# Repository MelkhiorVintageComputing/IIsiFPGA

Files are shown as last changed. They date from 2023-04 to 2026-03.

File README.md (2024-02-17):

# A FPGA on a IIsi PDS card...

## Goal

The goal of this repository is to be able to interface a modern (2023 era) [FPGA](https://en.wikipedia.org/wiki/Field-programmable_gate_array) with a [Macintosh IIsi](https://en.wikipedia.org/wiki/Macintosh_IIsi) using its PDS (Processor Direct Slot) connector. The PDS is basically just a physical connector to the MC68030 memory bus.

So unless you're a retrocomputing enthusiast with such a machine, this is useless. If you are such an enthusiast, then maybe the ability to connect a modern LCD monitor using a digital interface to an old Macintosh might be of interest to you.

This project was 'spun off' the [NuBusFPGA](https://github.com/rdolbeau/NuBusFPGA), a similar project for the NuBus used in several models of Macintosh of the era. NuBusFPGA itself is a spin-off of the [SBusFPGA](https://github.com/rdolbeau/SBusFPGA), a similar project for the SBus used in Sun's SPARCstation.

## Current status

The HDMI (Highly Desirable Macintosh Interface) is working, with both video (single-hardware-res, multi-depth, windowboxed lower res) & audio working. More details are available in the readme of the NuBusFPGA repository.

There's also experimental support to expose 240 MiB of DDR3 as additional memory to the host system, but that requires a patched ROM, typically using a modern Flash-based 'ROM SIMM'. Burst reads are supported for that use case, reading 16 bytes at a time from the DDR3 using a dedicated port, giving X-1-1-1 burst timings.

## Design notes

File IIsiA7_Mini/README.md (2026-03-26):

# IIsiA7 Mini

## Known issues in V3.0

* The JTAG header is not wired as intended (doesn't follow any pinouts I know), but the silkscreen is correct and it can be used just fine
* Pinout silkscreen for leds D4 and D5 is switched (D4 <=> D6), D6 is really top and D4 bottom)
* IRQs and CACHE should have had pull (up for IRQs, down for CACHE), the gateware currently enables pulling at the FPGA pins

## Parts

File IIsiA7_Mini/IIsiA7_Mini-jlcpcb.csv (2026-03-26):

Comment | Designator | Footprint
0402WGF0000TCE | R6,R21,R49,R52 | Resistor_SMD:R_0402_1005Metric
0402WGF1001TCE | R46,R48,R51 | Resistor_SMD:R_0402_1005Metric
0402WGF1002TCE | R7,R8,R9,R10,R24,R38,R39,R40,R42,R45,R47,R50 | Resistor_SMD:R_0402_1005Metric
0402WGF1003TCE | R25,R26,R27 | Resistor_SMD:R_0402_1005Metric
0402WGF330JTCE | R22,R23 | Resistor_SMD:R_0402_1005Metric
0402WGF4701TCE | R1,R2,R3,R11,R17,R18,R19,R20,R53 | Resistor_SMD:R_0402_1005Metric
0402WGF499JTCE | R12,R13,R14,R15,R16 | Resistor_SMD:R_0402_1005Metric
0402WGF5100TCE | R35,R36,R37,R41,R43 | Resistor_SMD:R_0402_1005Metric
10029449-111RLF | J1 | ForJLPCB:HDMI_A_Amphenol_10029449-111
1206B102K202NT | C97 | Capacitor_SMD:C_1206_3216Metric
650906-5 | J2 | ForJLCPCB:6509065
694106301002 | J11 | Connector_BarrelJack:BarrelJack_Wuerth_6941xx301002
AP1606 | Q1,Q2,Q3,Q4,Q5,Q6,Q7,Q9 | Package_DFN_QFN:Diodes_DFN1006-3
CH340N | U5 | Package_SO:JEITA_SOIC-8_3.9x4.9mm_P1.27mm
CL05A474KA5NNNC | C20,C21,C22,C23,C24,C25,C31,C33,C34,C35,C37,C41,C42,C43,C45,C48,C49,C50,C51,C52,C53,C54,C55,C60,C63,C65,C66,C67,C68,C70,C72,C74,C75,C76,C77,C121 | Capacitor_SMD:C_0402_1005Metric
CL05A475MP5NRNC | C26,C27,C32,C38,C44,C46,C57,C58,C59,C61,C62,C64,C71,C73,C120,C122 | Capacitor_SMD:C_0402_1005Metric
CL05B103KB5NNNC | C86,C92 | Capacitor_SMD:C_0402_1005Metric
CL05B104KB54PNC | C1,C2,C3,C4,C5,C6,C7,C8,C9,C10,C11,C12,C13,C14,C16,C17,C29,C30,C79,C81,C82,C83,C84,C94,C95,C96,C110,C112,C113,C114,C115,C117,C118,C119 | Capacitor_SMD:C_0402_1005Metric
CL10A105KB8NNNC | C15,C18,C19,C80 | Capacitor_SMD:C_0603_1608Metric
CL31A107MQHNNNE | C28,C36,C39,C40,C47,C56,C69,C78 | Capacitor_SMD:C_1206_3216Metric
CL31A226KAHNNNE | C85,C87,C88,C89,C91,C93,C98,C100,C103,C108,C111,C125 | Capacitor_SMD:C_1206_3216Metric
CPF0402B453KE1 | R33 | Resistor_SMD:R_0402_1005Metric
DW254W-22-12-85 | J3 | Connector_PinSocket_2.54mm:PinSocket_2x06_P2.54mm_Horizontal
FTC322512SR47MBCB | L1,L2,L8 | Inductor_SMD:L_Changjiang_FTC322512S
GRM1555C1H121GA01D | C90,C99,C143 | Capacitor_SMD:C_0402_1005Metric
HR1206J1M00P05Z | R31 | Resistor_SMD:R_1206_3216Metric
KT-0603R | D1,D2,D3,D4,D5,D6,D7,D9 | LED_SMD:LED_0603_1608Metric
LM3881MMX/NOPB | U4 | Package_SO:VSSOP-8_3x3mm_P0.65mm
MICROXNJ | J4,J5 | ForJLCPCB:MICROXNJ
PZ254V-11-06P | J13 | Connector_PinHeader_2.54mm:PinHeader_1x06_P2.54mm_Vertical
RT0402BRD07100KL | R29,R32,R34 | Resistor_SMD:R_0402_1005Metric
RT0402BRD07100RL | R44 | Resistor_SMD:R_0402_1005Metric
RT0402BRD071KL | R4,R5 | Resistor_SMD:R_0402_1005Metric
RT0402BRD07200KL | R30 | Resistor_SMD:R_0402_1005Metric
RT0402BRD0766K5L | R28 | Resistor_SMD:R_0402_1005Metric
SN74CB3T16211DGGR | IC3,IC4,IC5,IC6 | Package_SO:TSSOP-56_6.1x14mm_P0.5mm
SN74LVC1G125DCKR | U7 | Package_TO_SOT_SMD:Texas_R-PDSO-G5_DCK-5
SX3M100.000B20F30TNN | X1 | Oscillator:Oscillator_SMD_Abracon_ASE-4Pin_3.2x2.5mm
SX3M54.000M20F30TNN | X2 | Oscillator:Oscillator_SMD_Abracon_ASE-4Pin_3.2x2.5mm
T520B157M006ATE035 | C107,C116,C124 | Capacitor_Tantalum_SMD:CP_EIA-3528-21_Kemet-B
T520B337M2R5ATE009 | C102,C106,C123 | Capacitor_Tantalum_SMD:CP_EIA-3528-21_Kemet-B
TL3342F | PwrCtrlReset1 | Button_Switch_SMD:SW_SPST_TL3342
TPD12S016PWR | U3 | Package_SO:TSSOP-24_4.4x7.8mm_P0.65mm
TPS62823DLCR | U11,U12,U13 | Package_SON:Texas_VSON-HR-8_1.5x2mm_P0.5mm
W25Q128JVSIQ | U2 | Package_SO:SOIC-8_5.3x5.3mm_P1.27mm
W971GG6NB25I | IC1 | BGA84C80P9X15_900X1250X120
XC7A50T-1FTG256I | U1 | Package_BGA:Xilinx_FTG256

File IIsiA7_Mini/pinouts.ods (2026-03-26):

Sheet: xc7a100tftg256pkg
Device/Package | xc7a100tftg256
Pin | Pin
K12 | IO_0_14 | SERIAL_RX
J13 | IO_L1P_T0_D00_MOSI_14 | FLASH
J14 | IO_L1N_T0_D01_DIN_14 | FLASH
K15 | IO_L2P_T0_D02_14 | FLASH
K16 | IO_L2N_T0_D03_14 | FLASH
L15 | IO_L3P_T0_DQS_PUDC_B_14 | rsvd
M15 | IO_L3N_T0_DQS_EMCCLK_14 | rsvd
L14 | IO_L4P_T0_D04_14 | D9
M14 | IO_L4N_T0_D05_14 | D15
K13 | IO_L5P_T0_D06_14 | D7
L13 | IO_L5N_T0_D07_14 | D11
L12 | IO_L6P_T0_FCS_B_14 | FLASH
M12 | IO_L6N_T0_D08_VREF_14 | D21
M16 | IO_L7P_T1_D09_14 | D4
N16 | IO_L7N_T1_D10_14 | D6
P15 | IO_L8P_T1_D11_14 | D12
P16 | IO_L8N_T1_D12_14 | D8
R15 | IO_L9P_T1_DQS_14 | D13
R16 | IO_L9N_T1_DQS_D13_14 | D10
T14 | IO_L10P_T1_D14_14 | D17
T15 | IO_L10N_T1_D15_14 | D14
N13 | IO_L11P_T1_SRCC_14 | C16M
P13 | IO_L11N_T1_SRCC_14 | D18
N14 | IO_L12P_T1_MRCC_14 | CLK100
P14 | IO_L12N_T1_MRCC_14 | D16
N11 | IO_L13P_T2_MRCC_14 | CPUCLK
N12 | IO_L13N_T2_MRCC_14 | D24
P10 | IO_L14P_T2_SRCC_14 | D29
P11 | IO_L14N_T2_SRCC_14 | D26
R12 | IO_L15P_T2_DQS_RDWR_B_14 | D22
T12 | IO_L15N_T2_DQS_DOUT_CSO_B_14 | D23
R13 | IO_L16P_T2_CSI_B_14 | D19
T13 | IO_L16N_T2_A15_D31_14 | D20
R10 | IO_L17P_T2_A14_D30_14 | D27
R11 | IO_L17N_T2_A13_D29_14 | D25
N9 | IO_L18P_T2_A12_D28_14 | D30
P9 | IO_L18N_T2_A11_D27_14 | A31
M6 | IO_L19P_T3_A10_D26_14 | A20
N6 | IO_L19N_T3_A09_D25_VREF_14 | A23
P8 | IO_L20P_T3_A08_D24_14 | A28
R8 | IO_L20N_T3_A07_D23_14 | A30
T7 | IO_L21P_T3_DQS_14 | A26
T8 | IO_L21N_T3_DQS_A06_D22_14 | A29
T9 | IO_L22P_T3_A05_D21_14 | D31
T10 | IO_L22N_T3_A04_D20_14 | D28
R5 | IO_L23P_T3_A03_D19_14 | A22
T5 | IO_L23N_T3_A02_D18_14 | A21
R6 | IO_L24P_T3_A01_D17_14 | A24
R7 | IO_L24N_T3_A00_D16_14 | A28
P6 | IO_25_14 | A25
D10 | IO_0_15 | SERIALTX
C8 | IO_L1P_T0_AD0P_15 | PMOD_12
C9 | IO_L1N_T0_AD0N_15 | PMOD_11
A8 | IO_L2P_T0_AD8P_15 | PMOD_10
A9 | IO_L2N_T0_AD8N_15 | PMOD_9
B9 | IO_L3P_T0_DQS_AD1P_15 | HDMI_D2+
A10 | IO_L3N_T0_DQS_AD1N_15 | HDMI_D2-
B10 | IO_L4P_T0_15 | HDMI_D1+
B11 | IO_L4N_T0_15 | HDMI_D1-
B12 | IO_L5P_T0_AD9P_15 | HDMI_D0+
A12 | IO_L5N_T0_AD9N_15 | HDMI_D0--
D8 | IO_L6P_T0_15 | PMOD_7
D9 | IO_L6N_T0_VREF_15 | PMOD_8
A13 | IO_L7P_T1_AD2P_15 | HDMI_CLK+
A14 | IO_L7N_T1_AD2N_15 | HDMI_CLK-
C14 | IO_L8P_T1_AD10P_15 | CIOUT_n
B14 | IO_L8N_T1_AD10N_15 | TM0A_n
B15 | IO_L9P_T1_DQS_AD3P_15 | IRQ3_n
A15 | IO_L9N_T1_DQS_AD3N_15 | TM1A_n
C16 | IO_L10P_T1_AD11P_15 | STERM_n
B16 | IO_L10N_T1_AD11N_15 | IRQ1_n
C11 | IO_L11P_T1_SRCC_15 | RBV_n
C12 | IO_L11N_T1_SRCC_15 | CACHE_n
D13 | IO_L12P_T1_MRCC_15 | CLK54
C13 | IO_L12N_T1_MRCC_15 | IRQ2_n
E12 | IO_L13P_T2_MRCC_15 | CBACK_n
E13 | IO_L13N_T2_MRCC_15 | DSACK_n9
E11 | IO_L14P_T2_SRCC_15 | PMOD_6
D11 | IO_L14N_T2_SRCC_15 | PMOD_5
D14 | IO_L15P_T2_DQS_15 | DS_n
D15 | IO_L15N_T2_DQS_ADV_B_15 | CBREQ_n
F12 | IO_L16P_T2_A28_15 | BR_n
F13 | IO_L16N_T2_A27_15 | BGACK_n
E16 | IO_L17P_T2_A26_15 | SIZ1
D16 | IO_L17N_T2_A25_15 | DSACK_n1
F15 | IO_L18P_T2_A24_15 | AS_n
E15 | IO_L18N_T2_A23_15 | RW_n
H11 | IO_L19P_T3_A22_15 | D5
G12 | IO_L19N_T3_A21_VREF_15 | RESET_n
H12 | IO_L20P_T3_A20_15 | D3
H13 | IO_L20N_T3_A19_15 | D2
G14 | IO_L21P_T3_DQS_15 | FC0
F14 | IO_L21N_T3_DQS_A18_15 | SIZE0
H16 | IO_L22P_T3_A17_15 | FC1
G16 | IO_L22N_T3_A16_15 | BG_n
J15 | IO_L23P_T3_FOE_B_15 | D0
J16 | IO_L23N_T3_FWE_B_15 | BERR_n
H14 | IO_L24P_T3_RS1_15 | D1
G15 | IO_L24N_T3_RS0_15 | FC2
G11 | IO_25_15 | HALT_n
L5 | IO_0_34 | A4
L4 | IO_L1P_T0_34 | A2
M4 | IO_L1N_T0_34 | A7
M2 | IO_L2P_T0_34 | A1
M1 | IO_L2N_T0_34 | A0
N3 | IO_L3P_T0_DQS_34 | A8
N2 | IO_L3N_T0_DQS_34 | A5
N1 | IO_L4P_T0_34 | A3
P1 | IO_L4N_T0_34 | A6
P4 | IO_L5P_T0_34 | A17
P3 | IO_L5N_T0_34 | A10
M5 | IO_L6P_T0_34 | A16
N4 | IO_L6N_T0_VREF_34 | A11
R2 | IO_L7P_T1_34 | A13
R1 | IO_L7N_T1_34 | A9
R3 | IO_L8P_T1_34 | A14
T2 | IO_L8N_T1_34 | A12
T4 | IO_L9P_T1_DQS_34 | A18
T3 | IO_L9N_T1_DQS_34 | A15
P5 | IO_L10P_T1_34 | A19
E6 | IO_0_35 | LED_E6
B7 | IO_L1P_T0_AD4P_35
A7 | IO_L1N_T0_AD4N_35
B6 | IO_L2P_T0_AD12P_35
B5 | IO_L2N_T0_AD12N_35
A5 | IO_L3P_T0_DQS_AD5P_35
A4 | IO_L3N_T0_DQS_AD5N_35
B4 | IO_L4P_T0_35
A3 | IO_L4N_T0_35
C7 | IO_L5P_T0_AD13P_35
C6 | IO_L5N_T0_AD13N_35
D6 | IO_L6P_T0_35 | LED_D6
D5 | IO_L6N_T0_VREF_35
C3 | IO_L7P_T1_AD6P_35
C2 | IO_L7N_T1_AD6N_35
B2 | IO_L8P_T1_AD14P_35
A2 | IO_L8N_T1_AD14N_35
C1 | IO_L9P_T1_DQS_AD7P_35
B1 | IO_L9N_T1_DQS_AD7N_35
E2 | IO_L10P_T1_AD15P_35
D1 | IO_L10N_T1_AD15N_35
E3 | IO_L11P_T1_SRCC_35
D3 | IO_L11N_T1_SRCC_35
D4 | IO_L12P_T1_MRCC_35 | LED_D4
C4 | IO_L12N_T1_MRCC_35
F5 | IO_L13P_T2_MRCC_35
E5 | IO_L13N_T2_MRCC_35
F4 | IO_L14P_T2_SRCC_35
F3 | IO_L14N_T2_SRCC_35
F2 | IO_L15P_T2_DQS_35
E1 | IO_L15N_T2_DQS_35
G5 | IO_L16P_T2_35
G4 | IO_L16N_T2_35
G2 | IO_L17P_T2_35
G1 | IO_L17N_T2_35
H5 | IO_L18P_T2_35
H4 | IO_L18N_T2_35
J5 | IO_L19P_T3_35
J4 | IO_L19N_T3_VREF_35
H2 | IO_L20P_T3_35
H1 | IO_L20N_T3_35
J3 | IO_L21P_T3_DQS_35
H3 | IO_L21N_T3_DQS_35
K1 | IO_L22P_T3_35
J1 | IO_L22N_T3_35
L3 | IO_L23P_T3_35
L2 | IO_L23N_T3_35
K3 | IO_L24P_T3_35
K2 | IO_L24N_T3_35
K5 | IO_25_35 | LED_K5

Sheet: Sheet2
M1 | IO_L2N_T0_34 | A00
M2 | IO_L2P_T0_34 | A01
L4 | IO_L1P_T0_34 | A02
N1 | IO_L4P_T0_34 | A03
L5 | IO_0_34 | A04
N2 | IO_L3N_T0_DQS_34 | A05
P1 | IO_L4N_T0_34 | A06
M4 | IO_L1N_T0_34 | A07
N3 | IO_L3P_T0_DQS_34 | A08
R1 | IO_L7N_T1_34 | A09
P3 | IO_L5N_T0_34 | A10
N4 | IO_L6N_T0_VREF_34 | A11
T2 | IO_L8N_T1_34 | A12
R2 | IO_L7P_T1_34 | A13
R3 | IO_L8P_T1_34 | A14
T3 | IO_L9N_T1_DQS_34 | A15
M5 | IO_L6P_T0_34 | A16
P4 | IO_L5P_T0_34 | A17
T4 | IO_L9P_T1_DQS_34 | A18
P5 | IO_L10P_T1_34 | A19
M6 | IO_L19P_T3_A10_D26_14 | A20
T5 | IO_L23N_T3_A02_D18_14 | A21
R5 | IO_L23P_T3_A03_D19_14 | A22
N6 | IO_L19N_T3_A09_D25_VREF_14 | A23
R6 | IO_L24P_T3_A01_D17_14 | A24
P6 | IO_25_14 | A25
T7 | IO_L21P_T3_DQS_14 | A26
P8 | IO_L20P_T3_A08_D24_14 | A28
R7 | IO_L24N_T3_A00_D16_14 | A28
T8 | IO_L21N_T3_DQS_A06_D22_14 | A29
R8 | IO_L20N_T3_A07_D23_14 | A30
P9 | IO_L18N_T2_A11_D27_14 | A31
F15 | IO_L18P_T2_A24_15 | AS_n
J16 | IO_L23N_T3_FWE_B_15 | BERR_n
G16 | IO_L22N_T3_A16_15 | BG_n
F13 | IO_L16N_T2_A27_15 | BGACJKn
F12 | IO_L16P_T2_A28_15 | BR_n
N13 | IO_L11P_T1_SRCC_14 | C16M
C12 | IO_L11N_T1_SRCC_15 | CACHE_n
E12 | IO_L13P_T2_MRCC_15 | CBACK_n
D15 | IO_L15N_T2_DQS_ADV_B_15 | CBREQ_n
C14 | IO_L8P_T1_AD10P_15 | CIOUT_n
N14 | IO_L12P_T1_MRCC_14 | CLK100
D13 | IO_L12P_T1_MRCC_15 | CLK54
N11 | IO_L13P_T2_MRCC_14 | CPUCLK
J15 | IO_L23P_T3_FOE_B_15 | D00
H14 | IO_L24P_T3_RS1_15 | D01
H13 | IO_L20N_T3_A19_15 | D02
H12 | IO_L20P_T3_A20_15 | D03
M16 | IO_L7P_T1_D09_14 | D04
H11 | IO_L19P_T3_A22_15 | D05
N16 | IO_L7N_T1_D10_14 | D06
K13 | IO_L5P_T0_D06_14 | D07
P16 | IO_L8N_T1_D12_14 | D08
L14 | IO_L4P_T0_D04_14 | D09
R16 | IO_L9N_T1_DQS_D13_14 | D10
L13 | IO_L5N_T0_D07_14 | D11
P15 | IO_L8P_T1_D11_14 | D12
R15 | IO_L9P_T1_DQS_14 | D13
T15 | IO_L10N_T1_D15_14 | D14
M14 | IO_L4N_T0_D05_14 | D15
P14 | IO_L12N_T1_MRCC_14 | D16
T14 | IO_L10P_T1_D14_14 | D17
P13 | IO_L11N_T1_SRCC_14 | D18
R13 | IO_L16P_T2_CSI_B_14 | D19
T13 | IO_L16N_T2_A15_D31_14 | D20
M12 | IO_L6N_T0_D08_VREF_14 | D21
R12 | IO_L15P_T2_DQS_RDWR_B_14 | D22
T12 | IO_L15N_T2_DQS_DOUT_CSO_B_14 | D23
N12 | IO_L13N_T2_MRCC_14 | D24
R11 | IO_L17N_T2_A13_D29_14 | D25
P11 | IO_L14N_T2_SRCC_14 | D26
R10 | IO_L17P_T2_A14_D30_14 | D27
T10 | IO_L22N_T3_A04_D20_14 | D28
P10 | IO_L14P_T2_SRCC_14 | D29
N9 | IO_L18P_T2_A12_D28_14 | D30
T9 | IO_L22P_T3_A05_D21_14 | D31
D14 | IO_L15P_T2_DQS_15 | DS_n
E13 | IO_L13N_T2_MRCC_15 | DSACK_n0
D16 | IO_L17N_T2_A25_15 | DSACK_n1
G14 | IO_L21P_T3_DQS_15 | FC0
H16 | IO_L22P_T3_A17_15 | FC1
G15 | IO_L24N_T3_RS0_15 | FC2
J13 | IO_L1P_T0_D00_MOSI_14 | FLASH
J14 | IO_L1N_T0_D01_DIN_14 | FLASH
K15 | IO_L2P_T0_D02_14 | FLASH
K16 | IO_L2N_T0_D03_14 | FLASH
L12 | IO_L6P_T0_FCS_B_14 | FLASH
G11 | IO_25_15 | HALT_n
A14 | IO_L7N_T1_AD2N_15 | HDMI_CLK-
A13 | IO_L7P_T1_AD2P_15 | HDMI_CLK+
A12 | IO_L5N_T0_AD9N_15 | HDMI_D0--
B12 | IO_L5P_T0_AD9P_15 | HDMI_D0+
B11 | IO_L4N_T0_15 | HDMI_D1-
B10 | IO_L4P_T0_15 | HDMI_D1+
A10 | IO_L3N_T0_DQS_AD1N_15 | HDMI_D2-
B9 | IO_L3P_T0_DQS_AD1P_15 | HDMI_D2+
B16 | IO_L10N_T1_AD11N_15 | IRQ1_n
C13 | IO_L12N_T1_MRCC_15 | IRQ2_n
B15 | IO_L9P_T1_DQS_AD3P_15 | IRQ3_n
A8 | IO_L2P_T0_AD8P_15 | PMOD_10
C9 | IO_L1N_T0_AD0N_15 | PMOD_11
C8 | IO_L1P_T0_AD0P_15 | PMOD_12
D11 | IO_L14N_T2_SRCC_15 | PMOD_5
E11 | IO_L14P_T2_SRCC_15 | PMOD_6
D8 | IO_L6P_T0_15 | PMOD_7 | swapped ?
D9 | IO_L6N_T0_VREF_15 | PMOD_8 | swapped ?
A9 | IO_L2N_T0_AD8N_15 | PMOD_9
C11 | IO_L11P_T1_SRCC_15 | RBV_n
G12 | IO_L19N_T3_A21_VREF_15 | RESET_n
L15 | IO_L3P_T0_DQS_PUDC_B_14 | rsvd
M15 | IO_L3N_T0_DQS_EMCCLK_14 | rsvd
E15 | IO_L18N_T2_A23_15 | RW_n
K12 | IO_0_14 | SERIAL_RX
D10 | IO_0_15 | SERIALTX
F14 | IO_L21N_T3_DQS_A18_15 | SIZ0
E16 | IO_L17P_T2_A26_15 | SIZ1
C16 | IO_L10P_T1_AD11P_15 | STERM_n
B14 | IO_L8N_T1_AD10N_15 | TM0A_n
A15 | IO_L9N_T1_DQS_AD3N_15 | TM1A_n

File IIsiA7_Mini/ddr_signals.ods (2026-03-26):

BG1 |  | BG2 |  | BG3 |  | BG4
B7 |  | C3 |  | F5 |  | J5
A7 |  | C2 |  | E5 |  | J4
B6 |  | B2 |  | F4 |  | H2
B5 |  | A2 |  | F3 |  | H1
A5 |  | C1 |  | F2 |  | J3
A4 |  | B1 |  | E1 |  | H3
B4 |  | E2 |  | G5 |  | K1
A3 |  | D1 |  | G4 |  | J1
C7 |  | E3 |  | G2 |  | L3
C6 |  | D3 |  | G1 |  | L2
D6 |  | D4 |  | H5 |  | K3
D5 |  | C4 |  | H4 |  | K2
A7 | 14 | A2 | 6 | E5 | cke
B7 | dm1 | B2 | dm0 | F5 | ba2
C7 | 9 | B1 | ds0- | F4 | we
B6 | 12 | C1 | ds0+ | G5 | ba0
A5 | ds1+ | C2 | 1 | G4 | ras
A4 | ds1- | C3 | 7 | F3 | odt
B5 | 11 | D1 | 0 | E1 | cas
B4 | 15 | C4 | 4 | H5 | a0
A3 | 8 | D3 | 5 | F2 | a4
C6 | 10 | E2 | 2 | H4 | a11
D5 | 13 | E3 | 3 | G2 | a8
D6 |  | D4 |  | G1 | a13
 |  |  |  | H2 | a6
 |  |  |  | H1 | a2
 |  |  |  | H3 | clk_n
 |  |  |  | J3 | clk_p
 |  |  |  | J1 | ba1
 |  |  |  | J4 | a1
 |  |  |  | J5 | a10
 |  |  |  | K1 | a5
 |  |  |  | K2 | a3
 |  |  |  | K3 | a9
 |  |  |  | L2 | a7
 |  |  |  | L3 | a12
D1 | 0
C2 | 1
E2 | 2
E3 | 3
C4 | 4
D3 | 5
A2 | 6
C3 | 7
A3 | 8
C7 | 9
C6 | 10
B5 | 11
B6 | 12
D5 | 13
A7 | 14
B4 | 15
H5 | a00
J4 | a01
H1 | a02
K2 | a03
F2 | a04
K1 | a05
H2 | a06
L2 | a07
G2 | a08
K3 | a09
J5 | a10
H4 | a11
L3 | a12
G1 | a13
G5 | ba0
J1 | ba1
F5 | ba2
E1 | cas
E5 | cke
H3 | clk_n
J3 | clk_p
B2 | dm0
B7 | dm1
B1 | ds0-
C1 | ds0+
A4 | ds1-
A5 | ds1+
F3 | odt
G4 | ras
F4 | we

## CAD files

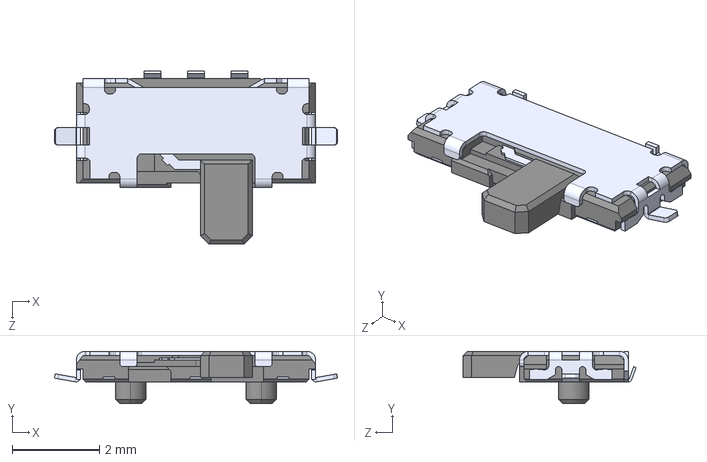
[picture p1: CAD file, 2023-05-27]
IIsi-to-ztex/SSAJ110100.step
6.50 x 1.20 x 3.98 mm

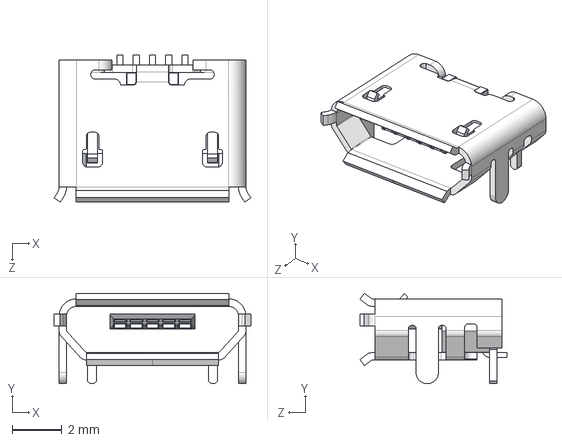
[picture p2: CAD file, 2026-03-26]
IIsiA7_Mini/MICROXNJ.stp
7.90 x 3.62 x 5.90 mm

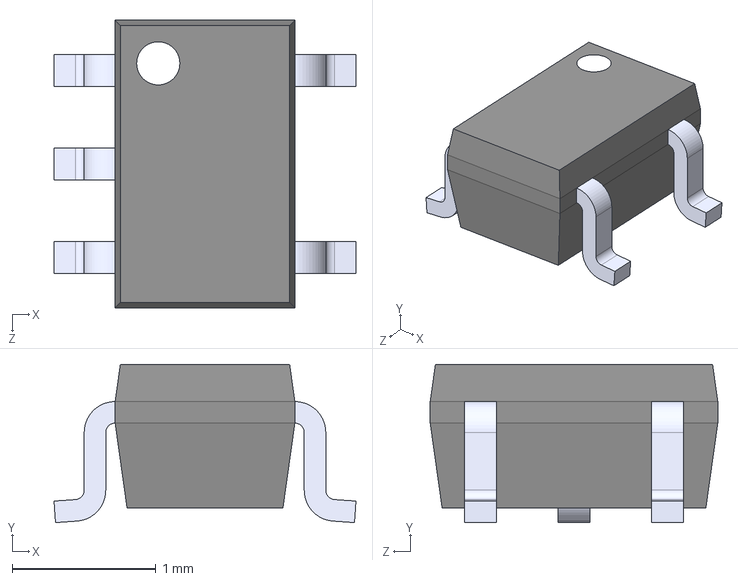
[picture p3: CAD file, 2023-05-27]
IIsi-to-ztex/SN74LV1T125DCKR.step
2.10 x 1.10 x 2.00 mm

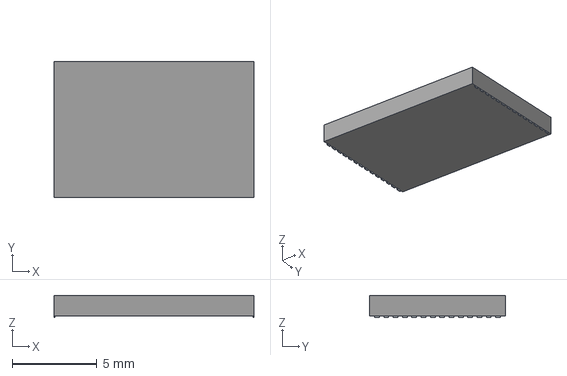
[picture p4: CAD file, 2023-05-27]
IIsi-to-ztex/IS61LV256AL-10TLI.stp
11.8 x 8.00 x 1.30 mm
Pins

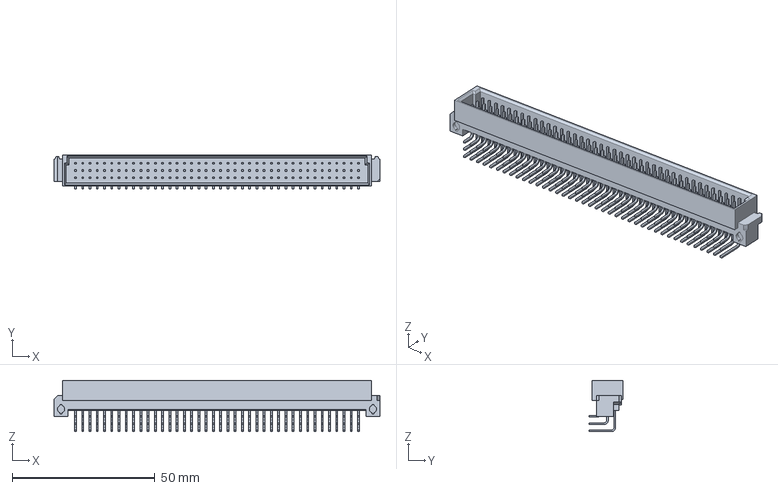
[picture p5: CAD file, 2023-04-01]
IIsi-to-ztex/650906-5.stp
114.2 x 12.1 x 18.0 mm

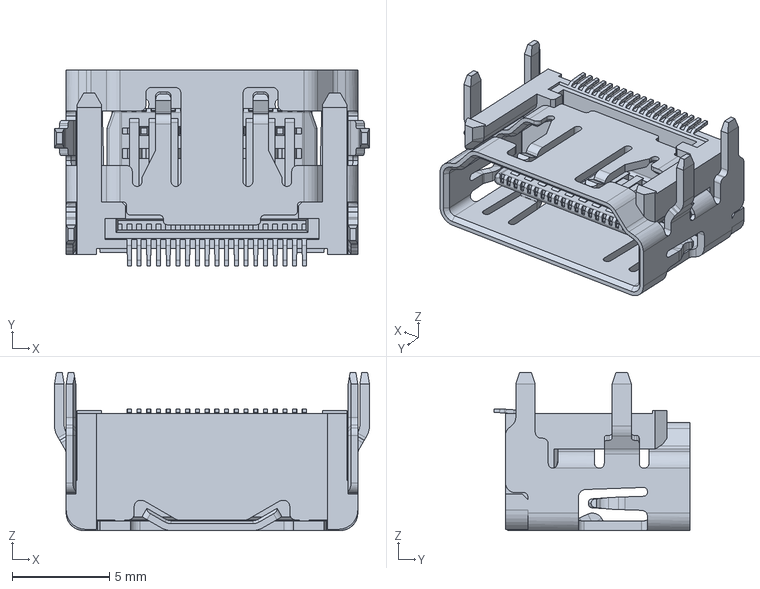
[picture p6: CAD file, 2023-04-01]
IIsi-to-ztex/10029449-111RLF.stp
16.2 x 10.1 x 8.13 mm

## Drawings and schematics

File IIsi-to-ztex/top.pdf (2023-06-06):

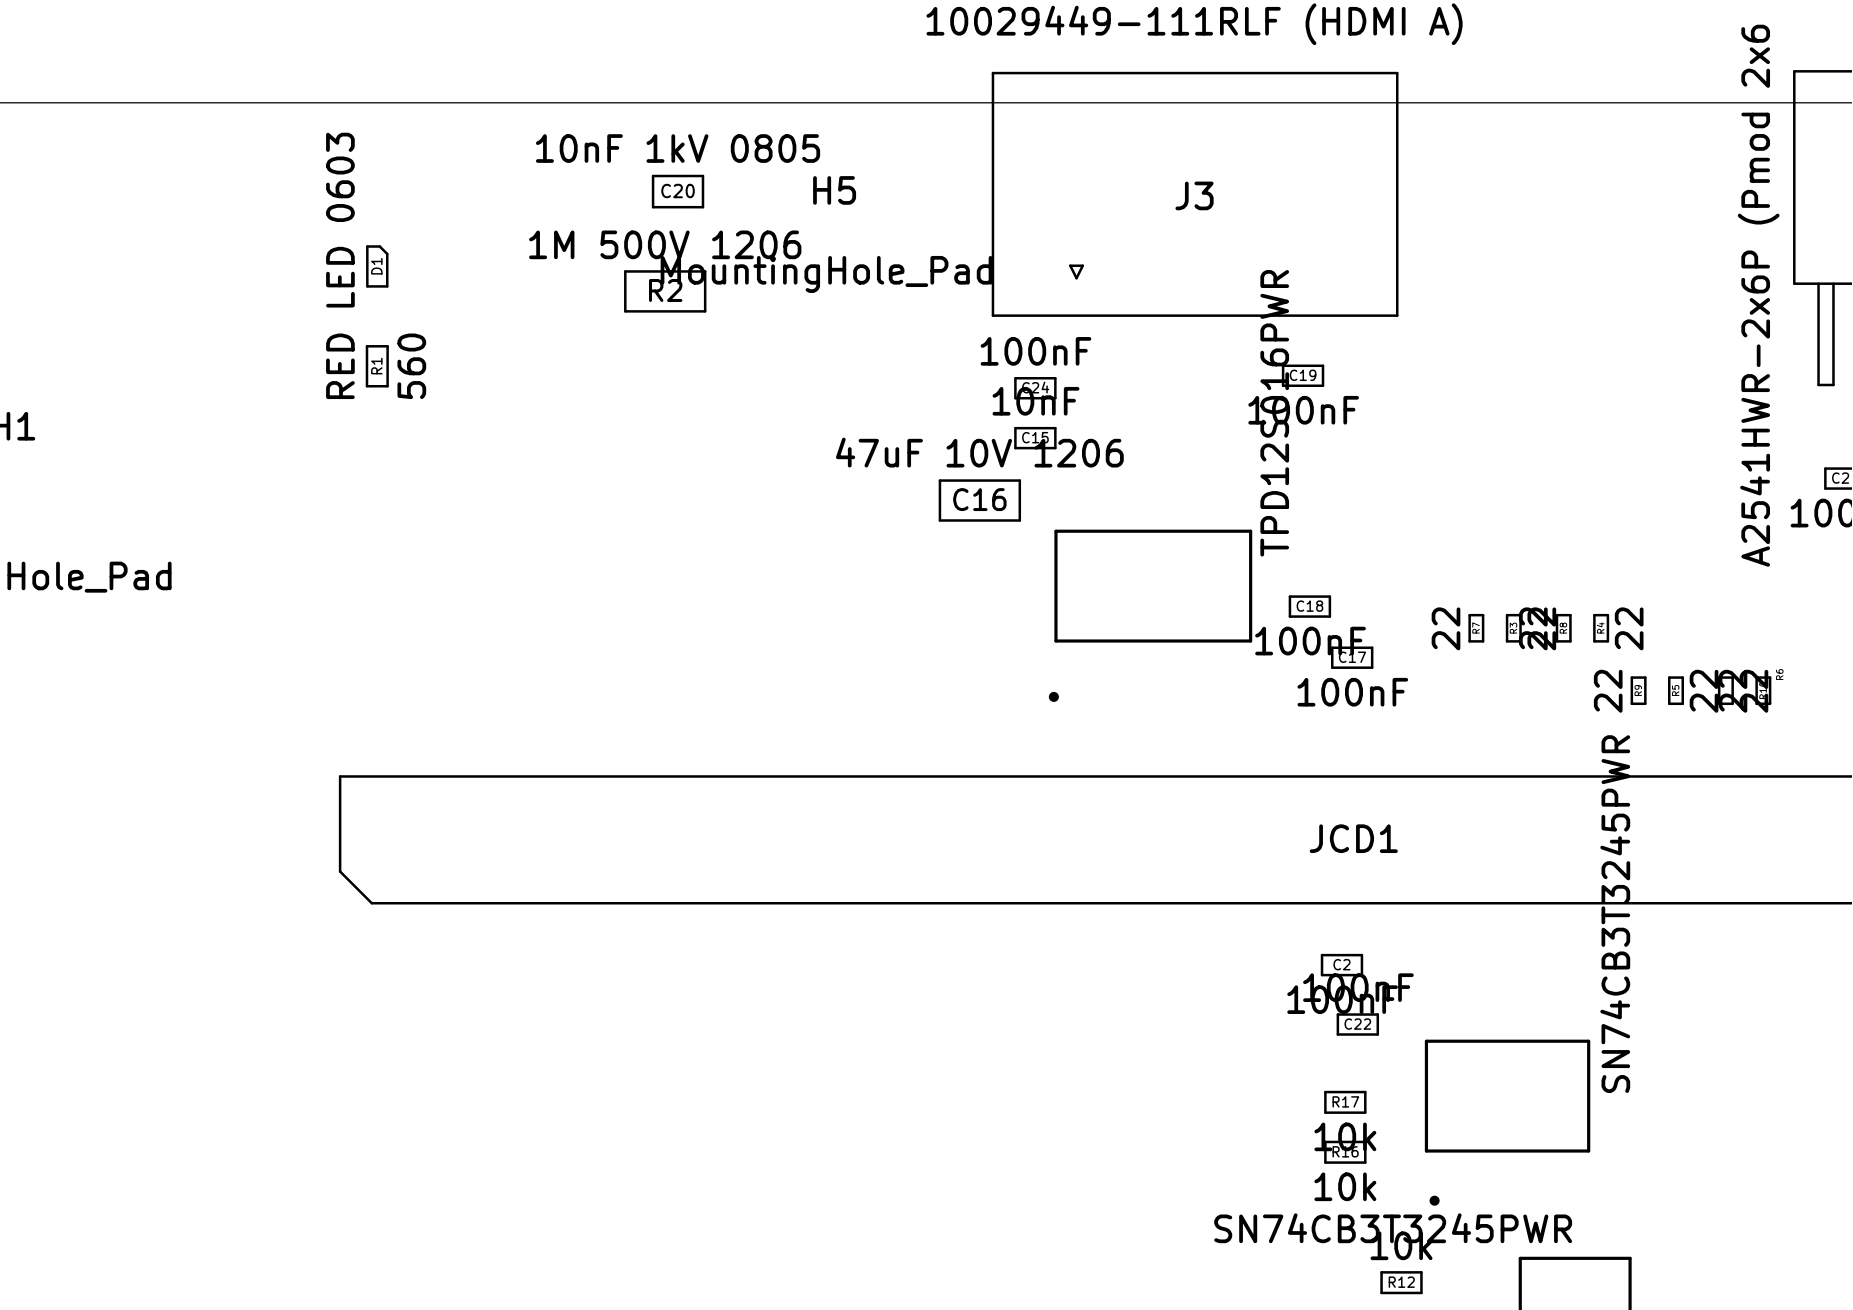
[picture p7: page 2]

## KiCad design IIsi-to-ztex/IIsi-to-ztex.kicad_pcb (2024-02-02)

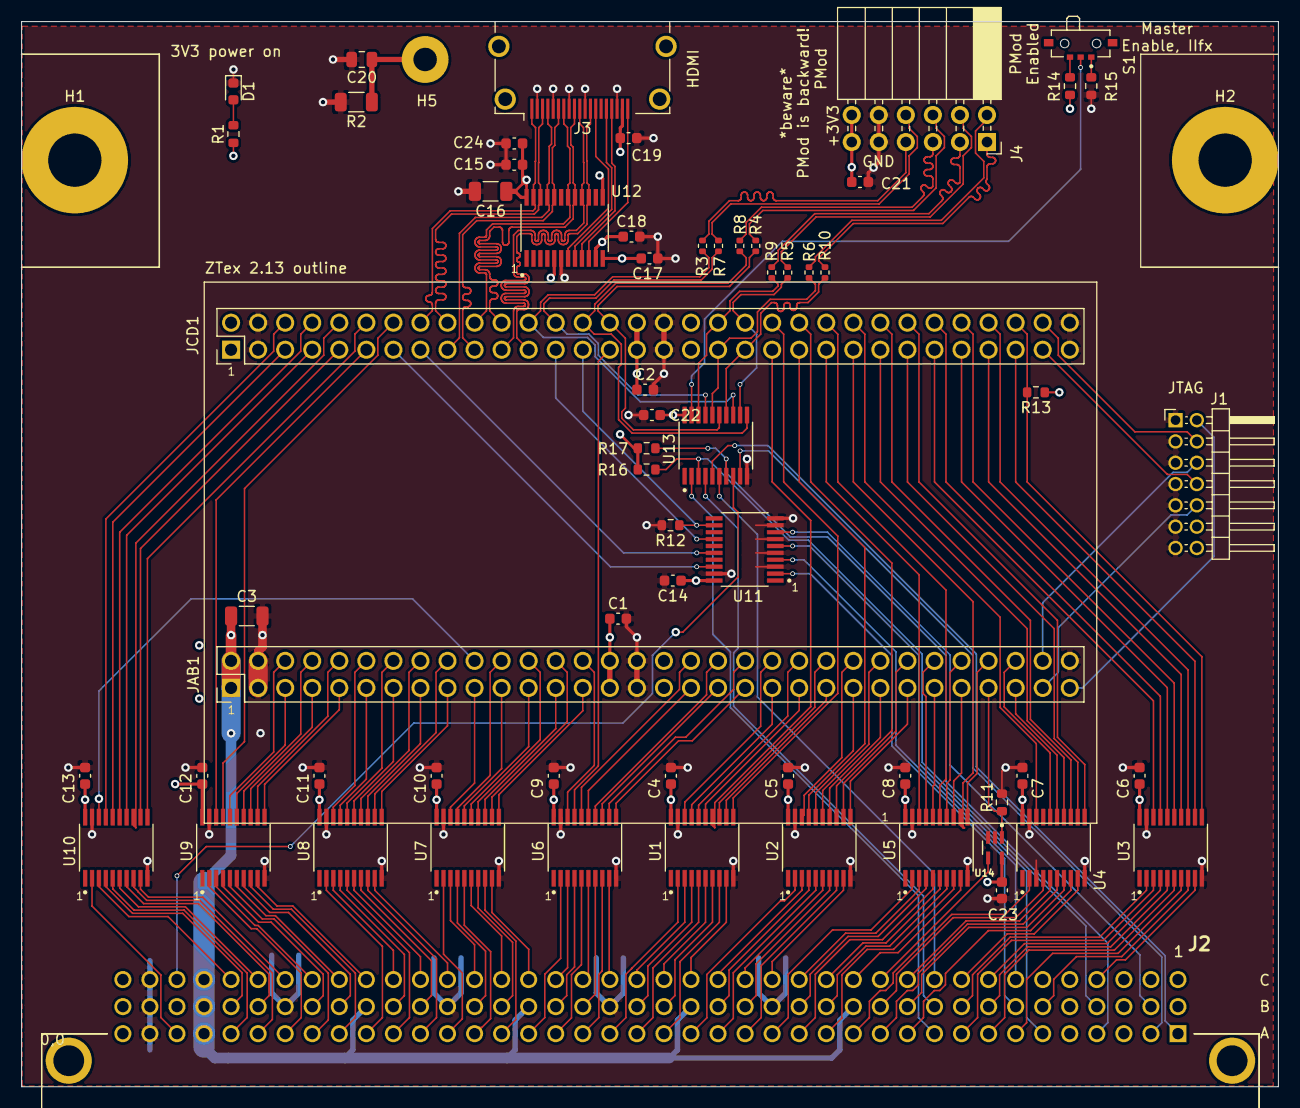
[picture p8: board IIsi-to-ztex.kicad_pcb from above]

Board: 4 copper layers, 118.0 x 100.0 mm, 66 parts (0 on the bottom side), 218 nets.

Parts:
C1, C2, C4, C5, C6, C7, C8, C9, C10, C11, C12, C13, C14, C17, C18, C19, C21, C22, C23, C24: 100nF; C_0603_1608Metric
C3: 47uF 10V+; C_1206_3216Metric
C15: 10nF; C_0603_1608Metric
C16: 47uF 10V 1206; C_1206_3216Metric
C20: 10nF 1kV 0805; C_0805_2012Metric
D1: RED LED 0603; LED_0603_1608Metric
H1, H2: MountingHole_Pad; MountingHole_5mm_Pad
H5: MountingHole_Pad; MountingHole_2.2mm_M2_Pad
J1: Conn_02x07_Odd_Even; PinHeader_2x07_P2.00mm_Horizontal_For_SeeedStudio
J2: 650906-5; 6509065
J3: 10029449-111RLF (HDMI A); HDMI_A_Amphenol_10029449-111
J4: A2541HWR-2x6P (Pmod 2x6 F R); PinSocket_2x06_P2.54mm_Horizontal
JAB1: ZTEX_AB-ztex_AB; PinHeader_2x32_P2.54mm_Vertical_For_SeeedStudio
JCD1: ZTEX_CD-ztex_CD; PinHeader_2x32_P2.54mm_Vertical_For_SeeedStudio
R1: 560; R_0603_1608Metric
R2: 1M 500V 1206; R_1206_3216Metric
R3, R4, R5, R6, R7, R8, R9, R10: 22; R_0402_1005Metric
R11, R12, R13, R14, R15, R16, R17: 10k; R_0603_1608Metric
S1: SSAJ110100; SW_SSAJ110100
U1, U2, U3, U4, U5, U6, U7, U8, U9, U10, U11, U13: SN74CB3T3245PWR; SOP65P640X120-20N
U12: TPD12S016PWR; SOP65P640X120-24N
U14: SN74LV1T125DCKR; SOT65P210X110-5N

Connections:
+3V3: C1.1, C2.1, C4.1, C5.1, C6.1, C7.1, C8.1, C9.1, C10.1, C11.1, C12.1, C13.1, C14.1, C15.1, C16.1, C17.1, C21.1, C22.1, C23.2, C24.1, J4.11, J4.12, JAB1.29, JAB1.30, JAB1.33, JAB1.34, JCD1.31, JCD1.32, JCD1.35, JCD1.36, R1.1, R13.1, R14.1, U1.20, U2.20, U3.20, U4.20, U5.20, U6.20, U7.20, U8.20, U9.20, U10.20, U11.20, U12.5, U12.12, U12.24, U13.20, U14.5
+5V: C3.1, C18.1, J2.A37, J2.B13, J2.B19, J2.B25, J2.B31, J2.B37, J2.C37, JAB1.1, JAB1.2, R16.1, R17.1, U12.11
/B2B/JTAG_VIO: J1.2, JAB1.63
/HDMI/HDMI_5V: C19.1, J3.18, U12.13
/HDMI/cec_b: J3.13, U12.7
/HDMI/hpd_b: J3.19, U12.10
/HDMI/scl_b: J3.15, U12.8
/HDMI/sda_b: J3.16, U12.9
/pmod/P56+: J4.7, R7.1
/pmod/P56-: J4.8, R3.2
/pmod/P78+: J4.5, R8.1
/pmod/P78-: J4.6, R4.2
/pmod/P910+: J4.3, R9.1
/pmod/P910-: J4.4, R5.2
/pmod/P1112+: J4.1, R10.1
/pmod/P1112-: J4.2, R6.2
A0: J2.C36, U10.3
A0_3V3: JCD1.6, U10.17
A1: J2.B36, U10.4
A1_3V3: JCD1.5, U10.16
A2: J2.A36, U10.5
A2_3V3: JCD1.8, U10.15
A3: J2.C35, U10.6
A3_3V3: JCD1.7, U10.14
A4: J2.B35, U10.7
A4_3V3: JCD1.10, U10.13
A5: J2.A35, U10.8
A5_3V3: JCD1.9, U10.12
A6: J2.C34, U10.9
A6_3V3: JCD1.12, U10.11
A7: J2.A34, U9.2
A7_3V3: JCD1.11, U9.18
A8: J2.C33, U9.3
A8_3V3: JCD1.14, U9.17
A9: J2.B33, U9.4
A9_3V3: JAB1.6, U9.16
A10: J2.A33, U9.5
A10_3V3: JAB1.5, U9.15
A11: J2.C32, U9.6
A11_3V3: JAB1.8, U9.14
A12: J2.B32, U9.7
A12_3V3: JAB1.7, U9.13
A13: J2.A32, U9.8
A13_3V3: JAB1.10, U9.12
A14: J2.C31, U9.9
A14_3V3: JAB1.9, U9.11
A15: J2.A31, U8.2
A15_3V3: JAB1.12, U8.18
A16: J2.C30, U8.3
A16_3V3: JAB1.11, U8.17
A17: J2.B30, U8.4
A17_3V3: JAB1.14, U8.16
A18: J2.A30, U8.5
A18_3V3: JAB1.13, U8.15
A19: J2.C29, U8.6
A19_3V3: JAB1.16, U8.14
A20: J2.B29, U8.7
A20_3V3: JAB1.15, U8.13
A21: J2.A29, U8.8
A21_3V3: JAB1.18, U8.12
A22: J2.C28, U8.9
A22_3V3: JAB1.17, U8.11
A23: J2.A28, U7.2
A23_3V3: JAB1.19, U7.18
A24: J2.C27, U7.3
A24_3V3: JAB1.22, U7.17
A25: J2.B27, U7.4
A25_3V3: JAB1.21, U7.16
A26: J2.A27, U7.5
A26_3V3: JAB1.23, U7.15
A27: J2.C26, U7.6
A27_3V3: JAB1.24, U7.14
A28: J2.B26, U7.7
A28_3V3: JAB1.25, U7.13
A29: J2.A26, U7.8
A29_3V3: JAB1.26, U7.12
A30: J2.C25, U7.9
A30_3V3: JAB1.27, U7.11
A31: J2.A25, U6.2
A31_3V3: JAB1.28, U6.18
C16M: J2.C38, U13.8
C16M_3V3: JCD1.40, R5.1, U13.12
CACHE: J2.B2, U11.8
CACHE_3V3: JCD1.27, R12.1, U11.12
CPUCLK: J2.A38, U10.2
CPUCLK_3V3: JAB1.20, U10.18
D0: J2.A13, U4.2
D0_3V3: JCD1.48, U4.18
D1: J2.C13, U5.9
D1_3V3: JAB1.58, U5.11
D2: J2.A14, U5.8
D2_3V3: JCD1.47, U5.12
D3: J2.B14, U5.7
D3_3V3: JAB1.55, U5.13
D4: J2.C14, U5.6
D4_3V3: JAB1.56, U5.14
D5: J2.A15, U5.5
D5_3V3: JCD1.46, U5.15
D6: J2.B15, U5.4
D6_3V3: JAB1.53, U5.16
D7: J2.C15, U5.3
D7_3V3: JAB1.54, U5.17
D8: J2.A16, U5.2
D8_3V3: JCD1.45, U5.18
D9: J2.C16, U2.9
D9_3V3: JAB1.51, U2.11
D10: J2.A17, U2.8
D10_3V3: JAB1.52, U2.12
D11: J2.B17, U2.7
D11_3V3: JCD1.44, U2.13
D12: J2.C17, U2.6
D12_3V3: JAB1.49, U2.14
D13: J2.A18, U2.5
D13_3V3: JAB1.50, U2.15
D14: J2.B18, U2.4
D14_3V3: JCD1.43, U2.16
D15: J2.C18, U2.3
D15_3V3: JAB1.47, U2.17
D16: J2.A19, U2.2
D16_3V3: JAB1.48, U2.18
D17: J2.C19, U1.9
D17_3V3: JCD1.42, U1.11
D18: J2.A20, U1.8
D18_3V3: JAB1.45, U1.12
D19: J2.B20, U1.7
D19_3V3: JAB1.46, U1.13
D20: J2.C20, U1.6
D20_3V3: JCD1.41, U1.14
D21: J2.A21, U1.5
D21_3V3: JAB1.43, U1.15
D22: J2.B21, U1.4
D22_3V3: JAB1.44, U1.16
D23: J2.C21, U1.3
D23_3V3: JAB1.41, U1.17
D24: J2.A22, U1.2
D24_3V3: JAB1.42, U1.18
D25: J2.C22, U6.9
D25_3V3: JAB1.39, U6.11
D26: J2.A23, U6.8
D26_3V3: JAB1.40, U6.12
D27: J2.B23, U6.7
D27_3V3: JAB1.37, U6.13
D28: J2.C23, U6.6
D28_3V3: JAB1.38, U6.14
D29: J2.A24, U6.5
D29_3V3: JAB1.35, U6.15
D30: J2.B24, U6.4
D30_3V3: JAB1.36, U6.16
D31: J2.C24, U6.3
D31_3V3: JCD1.29, U6.17
FC0: J2.C11, U4.5
FC0_3V3: JAB1.59, U4.15
FC1: J2.B11, U4.7
FC1_3V3: JCD1.50, U4.13
FC2: J2.A11, U4.8
FC2_3V3: JCD1.51, U4.12
FPGA_JTAG_TCK: J1.6, JAB1.62
FPGA_JTAG_TDI: J1.10, JAB1.61
FPGA_JTAG_TDO: J1.8, JCD1.61
FPGA_JTAG_TMS: J1.4, JCD1.62
GND: C1.2, C2.2, C3.2, C4.2, C5.2, C6.2, C7.2, C8.2, C9.2, C10.2, C11.2, C12.2, C13.2, C14.2, C15.2, C16.2, C17.2, C18.2, C19.2, C20.2, C21.2, C22.2, C23.1, C24.2, D1.1, J1.1, J1.3, J1.5, J1.7, J1.9, J1.11, J1.13, J2.A39, J2.B16, J2.B22, J2.B28, J2.B34, J2.B39, J2.C39, J3.2, J3.5, J3.8, J3.11, J3.17, J4.9, J4.10, JAB1.3, JAB1.4, JAB1.31, JAB1.32, JAB1.64, JCD1.3, JCD1.4, JCD1.33, JCD1.34, JCD1.63, JCD1.64, R2.2, R11.2, R12.2, R15.1, U1.10, U1.19, U2.10, U2.19, U3.10, U3.19, U4.3, U4.10, U4.19, U5.10, U5.19, U6.10, U6.19, U7.10, U7.19, U8.10, U8.19, U9.10, U9.19, U10.10, U10.19, U11.3, U11.5, U11.7, U11.9, U11.10, U11.19, U12.6, U13.10, U14.2, U14.3
HDMI_CLK+: J3.10, JCD1.21, U12.16
HDMI_CLK-: J3.12, JCD1.23, U12.15
HDMI_D0+: J3.7, JCD1.20, U12.18
HDMI_D0-: J3.9, JCD1.22, U12.17
HDMI_D1+: J3.4, JCD1.17, U12.21
HDMI_D1-: J3.6, JCD1.19, U12.20
HDMI_D2+: J3.1, JCD1.16, U12.23
HDMI_D2-: J3.3, JCD1.18, U12.22
unnamed: D1.2, R1.2
unnamed: R14.2, S1.2
unnamed: R15.2, S1.1
PMOD-56+: JCD1.24, R7.2, U13.13
PMOD-56-: JCD1.26, R3.1, U13.17
PMOD-78+: JCD1.28, R8.2, U13.11
PMOD-78-: JCD1.30, R4.1, U13.15
PMOD-910+: JCD1.38, R9.2, U13.18
PMOD-1112+: JCD1.39, R10.2, U13.14
PMOD-1112-: JCD1.37, R6.1, U13.16
SHIELD: C20.1, H5.1, J3.SH, R2.1
SIZ0: J2.B9, U3.2
SIZ0_3V3: JCD1.53, U3.18
SIZ1: J2.A9, U3.3
SIZ1_3V3: JCD1.54, U3.17
~AS: J2.C9, U4.9
~AS_3V3: JCD1.52, U4.11
~BERR: J2.B12, U4.4
~BERR_3V3: JAB1.60, U4.16
~BG: J2.B10, U13.4
~BGACK: J2.A10, U13.2
~BR: J2.C10, U13.6
~CBACK: J2.B7, U11.2
~CBACK_3V3: JCD1.13, U11.18
~CBREQ: J2.C7, U11.4
~CBREQ_3V3: JCD1.15, U11.16
~CIOUT: J2.A6, U11.6
~CIOUT_3V3: JCD1.25, U11.14
~DS: J2.B6, U3.8
~DSACK0: J2.B8, U3.5
~DSACK0_3V3: JCD1.56, U3.15
~DSACK1: J2.A8, U3.6
~DSACK1_3V3: JCD1.57, U3.14
~DS_3V3: JCD1.59, U3.12
~FPU: J2.A2, U13.9
~HALT: J2.C12, U14.4
~HALT_3V3: JAB1.57, R11.1, U14.1
~IRQ1: J2.C4, U3.9
~IRQ1_3V3: JCD1.60, R13.2, U3.11
~IRQ2: J2.B4, R16.2, U13.3
~IRQ3: J2.A4, R17.2, U13.7
~MASTER_OE: S1.C, U13.19
~RBV: J2.A1, U13.5
~RESET: J2.A12, U4.6
~RESET_3V3: JCD1.49, U4.14
~RW: J2.C8, U3.4
~RW_3V3: JCD1.55, U3.16
~STERM: J2.A7, U3.7
~STERM_3V3: JCD1.58, U3.13

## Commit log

2023-04-01 import draft to GH
    [10029449-111RLF.stp, 650906-5.stp, B2B.sch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]
2023-04-01 rework /HALT
    [B2B.sch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]
2023-05-16 cleanup DRC
    [B2B.sch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]
2023-05-27 extra stuff
    [IS61LV256AL-10TLI.stp, SN74LV1T125DCKR.step, SSAJ110100.step]
2023-06-03 connect rbv to last pmod pin
    [B2B.sch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]
2023-06-03 some rerouting
    [IIsi-to-ztex-B_Cu.gbr, IIsi-to-ztex-B_Mask.gbr, IIsi-to-ztex-B_Paste.gbr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]
2023-06-06 some pull-(up,down)s
    [IIsi-to-ztex-B_Cu.gbr, IIsi-to-ztex-B_Mask.gbr, IIsi-to-ztex-B_Paste.gbr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]
2023-06-13 catching up with PCB
2023-08-15 just in case
2023-11-18 move some of board platform stuff to common
2024-02-02 pmod orientation
    [IIsi-to-ztex.kicad_pcb]
2024-05-18 IIfx support (needs its own bitstream), board-based name
2024-09-01 down-conversion from Motorola's FP80 to IEEE FP32/FP64 (from patched flopoco)
2026-02-22 From Template
    [Artix-7 B14.kicad_sch, Artix-7 B34.kicad_sch, Artix-7 Support.kicad_sch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]
2026-03-21 fix BoM
    [board_specific.kicad_sch]
2026-03-25 V3.0 board files
2026-03-25 produciton files
    [IIsiA7_Mini-jlcpcb.csv, pinouts.ods, positions.csv]
2026-03-28 unify leds naming with IIsiA7 Mini
2026-03-28 grr, fix pin order

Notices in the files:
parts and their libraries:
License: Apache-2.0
